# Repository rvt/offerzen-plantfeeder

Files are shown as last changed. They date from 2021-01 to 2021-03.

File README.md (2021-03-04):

# Offerzen plantfeeder

This is software + box for the offerzen plantfeeder [plant_tech_ams](https://github.com/OfferZen-Make/plant_tech_ams)
Check `platform.io` for pin layout as I had to change the pin number for the motor that somehow did not work.

### Support

* Deep sleep
* sending messages over MQTT
* A little scripting language
* Web based configurating of WiFi and MQTT configurations
* Loos wire detection so the motor won't keep running if your sensor wires breaks
* Hysteresis so your motor won't turn off/on around threshold value
* STl + OpenSCAD in box directory, you might need to modify dimentions for your need 

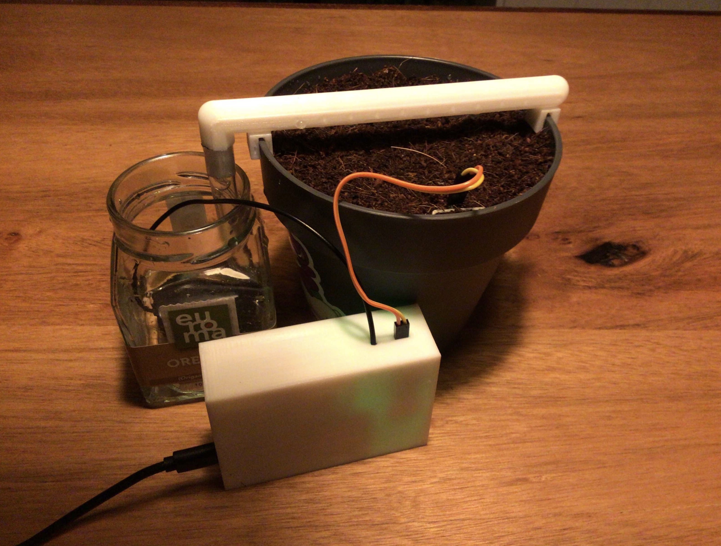
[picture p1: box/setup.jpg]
Total setup


## To Build you need PlatformIO

Use `platformio run --target upload -e default` to build and uploads.

Use `platformio run --target uploadfs -e default`to upload the needed filesystem.

## To Configure

* Look into your serial terminal and note your IP address and ID of your feeder.
* Use a webbrowser and fill in your WiFi and MQTT parameters

## PIN Connections

* Connection GPIO16 to the Reset pin
* Connect D8 to the VSS of the moisture sensor, we turn the moisture sensor on/off before and after a measurement to prevent corrision.
* Connect A0 to the analog out pin of the moisture sensor
* Connect GND of the moisture sensor to the GND of the ESP8266
* Connect D6 to the base (visa resistor) to the transistor to control the motor

## Set threshold values use MQTT and issue the following commands

* Topic: `plantfeeder/XXXXXXXX/config`
* Payload: `wet=400 dry=800`

Where `XXXXXXXX`is the ID for your plantfeeder, check a tool like MQTT Spy with plantfeeder/# to see your messages

When the measured value is below wet, then we are not adding any more water.
Consequently, when the measured value is above dry we will be adding more water;
* Dry should always be higher than wet, no protection against that
* The higher the measured value, the dryer the soil

No MQTT, No problem! Edit `data/hwCfg.conf`and fill in the values. (The L in front of the number is correct and not a typo, format is very strict, no spaces and integer only!)

## Enable/Disable deepSleep

To enable deepSleep

* Topic: `plantfeeder/XXXXXXXX/config`
* Payload: `deepSleepEnabled=1`

To disable deepSleep

* Topic: `plantfeeder/XXXXXXXX/config`
* Payload: `deepSleepEnabled=0`

## Scripting.

It uses a very little script and primitive to turn on/off the motor, see ´data/default.txt´ to change timings of the motor. If you want to add detecting of moisture levels within the script then look into
´scriptcontext.cpp´ and the ´scripting.cpp´ files or contact me and I can help.

To ensure that we don't keep the pump running on disconnect any value measured above `1020` is considered a disconnect and we won't run the engine to prevent flooding.

You can send on topic `plantfeeder/XXXXXXXX/load` with payload `/pump5.txt` to start the script (it will turn on the pump for 5 seconds) after that it will load the `default.txt` again. Be ware that during deep sleep nothing will happen, I have yet to test if after deep sleep it will load the script correctly (let me know).

## Deep Sleep
The device will enter deep sleep to conserve battery. you MUST connect GPIO16 to the RST pin with one of your dupont cable or else the device won't wake up. 
I did had issues with a powerpack that would turn of because the load was so low that the powerpack turned itself of.

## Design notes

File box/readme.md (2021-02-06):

## Box for your offzen plantfeeder

Slice the plantfeeder.stl and print with PLA. Infill set to 40% or higher and you should be good.

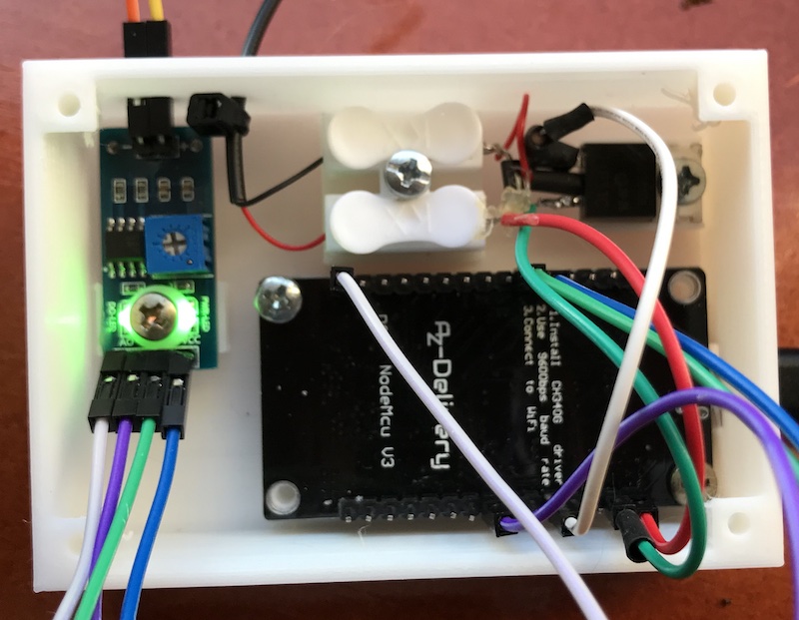
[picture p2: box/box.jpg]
Hardware wired up


* I added a flyback diode over the motor
* I added a resistor on the base of the TIP31C to limit currents.
* I have moved the terminal block more to the left to give the TIP31C more room

## Waterguide for your offzen plantfeeder

Slice the waterguide.stl and print with PLA, use a brim of 4mm use support for the sprout. CLean it up after printing.

Total setup

## New probe for your offzen plantfeeder

The soilProbe started to oxidize very quickly and I found it very sensitive.
This probe sticks much deeper in the soil making it much more sturdy and less sensitive.
Your A/D values will also be much lower (mine where like 100 for a wet soil instead of 300..400).
You properly want to modify the SCAD file before you print it to match the probe diameter (`probeDiam` in scad file)you have.
Mine where 6mm in diameter and I could solder them very easy. Perhaps some kopper wire you might have? 
Just print them with 100% infill and use a 3mm screw to put it together.

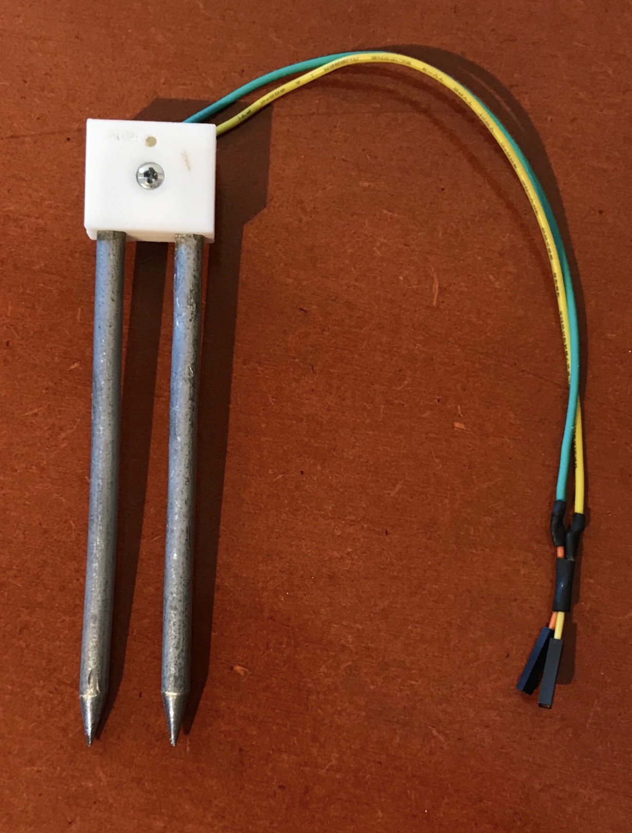
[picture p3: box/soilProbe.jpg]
soil probe


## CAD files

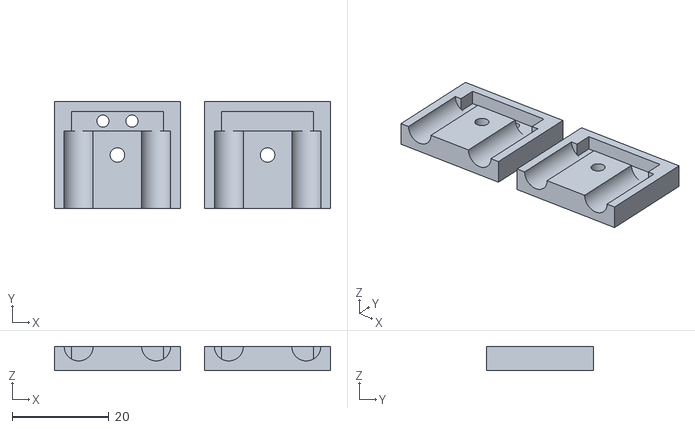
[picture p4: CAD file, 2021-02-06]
box/soilProbe.stl
57.0 x 22.0 x 5.00

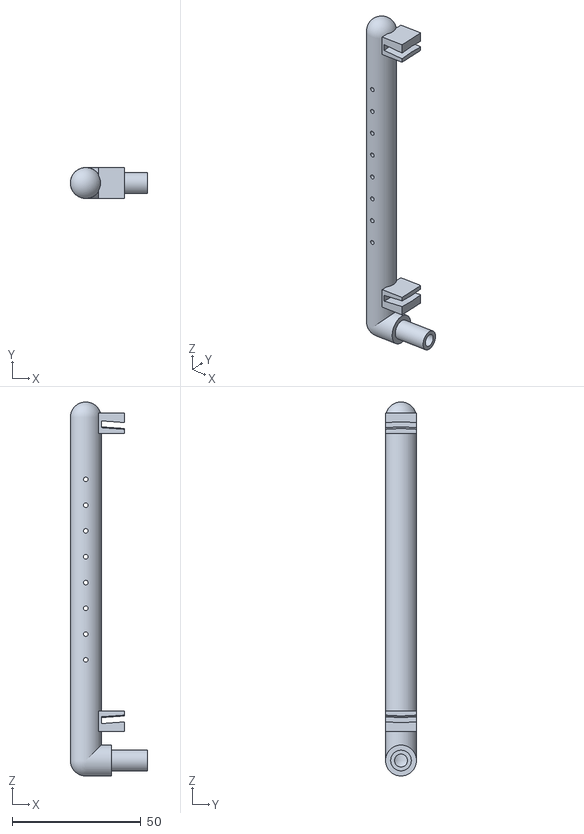
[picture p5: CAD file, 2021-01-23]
box/waterguide.stl
30.0 x 12.0 x 145.0

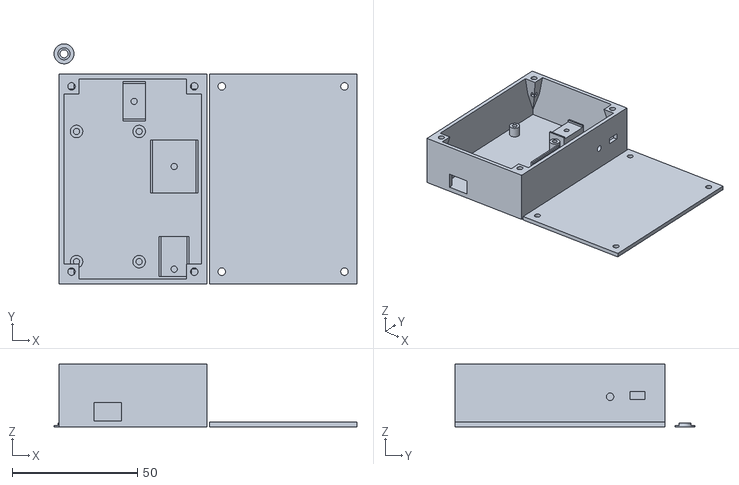
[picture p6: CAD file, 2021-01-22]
box/plantfeeder.stl
121.0 x 96.0 x 25.0

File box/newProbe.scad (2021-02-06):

$fn=60;

// Diameter of probe
probeDiam=6;        
// Spacing between probe
probeSpacing=16;
// THickness of wall
wall=2.0;

// Length of probe (Visual only)
probeLength=120;

// Diameter of screw
screwDiam=3;
// Height of screw head
screwHead=2.5;
// Diameter of screw head
screwHeadDiam=5.8;

///Offset probe from center of casing
probeEndOffset=5;

// Do not change below
wall2=wall*2;
probeSpacingD2=probeSpacing/2;
dim=[probeSpacing + probeDiam + wall2,probeEndOffset*2+4*2+wall2,probeDiam+wall2];

echo("Casing dimention ");
echo(dim);


soilProbe(true);
translate([dim.x+5,0,0]) soilProbe(false);

module soilProbe(bottom=true) {
    translate([0,0,dim.z/2])
    union() {
        difference() {
            union() {
                cube(dim, center=true);
                
            }
            union() {
                // Cut in half
                translate([0,0,dim.z/2]) cube(dim, center=true);

                // Room for Wire
                translate([0,probeEndOffset+2,0]) {
                    cube([probeSpacing+probeDiam/2,4,probeDiam], center=true);
                    if (bottom) {
                        translate([3,0,0]) cylinder(d=2.5,h=dim.z,center=true);
                        translate([-3,0,0]) cylinder(d=2.5,h=dim.z,center=true);
                    }
                }
                
                // Probe
                translate([probeSpacingD2,probeEndOffset,0]) probe();
                translate([-probeSpacingD2,probeEndOffset,0]) probe();      
                
                // screw Portion
                screw();
            }
        }

        %translate([probeSpacingD2,probeEndOffset,0]) probe();
        %translate([-probeSpacingD2,probeEndOffset,0]) probe();
    }
}


module screw() {
    cylinder(d=screwDiam,h=dim.z,center=true);
    translate([0,0,-dim.z/2+screwHead/2]) cylinder(d=screwHeadDiam,h=screwHead,center=true);
}    


module probe() {
    pointL=probeDiam*2.5;
    color([0.5,1,0.5]) rotate([90,0,0]) {
        cylinder(d=probeDiam,h=probeLength-pointL);
        translate([0,0,probeLength-pointL]) cylinder(d2=0, d1=probeDiam, h=probeDiam*2.5);
    }

}

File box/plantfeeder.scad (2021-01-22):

$fn=60;

boxX=55;
boxY=80;
boxZ=25;
wall=2;
screwSize=2.5;
diamMotorWire=3;

locationESP=[[5,7,0],[0,0,0]];
locationHydro=[[20+15,boxY-9,0], [0,0,90]];
locationTIPC31C=[[boxX-11,9,0], [0,0,0]];
locationKroon=[[boxX-11,boxY/2+5,0], [0,0,0]];
locationHoleMotor=[[boxX-5,boxY-20,boxZ-15], [0,90,0]];


// BOX&Stuff
difference() {
    union() {
        box();
        translate([-wall,-wall,-wall]) boxCornerTab(wall=wall,bottom=wall,innerWidth=boxX,innerLength=boxY,innerHeight=boxZ);
        TR(locationHydro) hygro(heightPcb=5, cut=false);
        TR(locationTIPC31C) color([1,0,0]) TIPC31C(heightPcb=5);
        TR(locationKroon) color([0,1,0]) kroon(heightPcb=5);
        TR(locationESP) esp8266_az(cut=false, heightPcb=5);
    }
    union() {
        translate([-wall,-wall,-wall]) boxCornerTab(wall=wall,bottom=wall,innerWidth=boxX,innerLength=boxY,innerHeight=boxZ,cut=true);
        TR(locationESP) esp8266_az(cut=true, heightPcb=5);
        TR(locationHydro) hygro(heightPcb=5, cut=true);
        TR(locationHoleMotor) cylinder(d=3,h=10);
    }
}

// Little ring
translate([0,boxY+10,-wall]) {
    difference() {
        union() {
            cylinder(d=3.2+4*0.4,h=1.5);
            cylinder(d=8,h=0.5);
        }
        cylinder(d=3.2,h=4);
    }
}

// LID
translate([60,0,0]) {
    difference() {
        lid();
            translate([-wall,-wall,-boxZ]) 
            boxCornerTab(wall=wall,bottom=wall,innerWidth=boxX,innerLength=boxY,innerHeight=boxZ,cut=true);
    }
}

module lid() {
    boxZ=wall;
    translate([boxX/2,boxY/2,boxZ/2-wall])
    cube([boxX+wall*2, boxY+wall*2, boxZ], center=true);
}


// Translate and Rotate
module TR(in) {
    translate(in[0]) rotate(in[1]) children();
}

module box() {
    translate([boxX/2,boxY/2,boxZ/2-wall])
        difference() {        
            cube([boxX+wall*2, boxY+wall*2, boxZ], center=true);
            translate([0,0,wall]) cube([boxX, boxY, boxZ], center=true);
        }
}

module esp8266_az(heightPcb=7, cut=false) {
    pos=[
        [0,0],
        [25,0],
        [0,52],
        [25,52]
    ];
    board=[[-3,-3],[31,57]];
    if (cut) {
        translate([0,0,heightPcb]+[0,0,-1.5]) 
        translate(board[0] + [0-11/2 + board[1].x/2,-17,0]) 
        translate([0,0,-3.2]) cube([11,17,7.4]);
    } else {
        %difference() {
            translate([0,0,heightPcb]) translate(board[0]) linear_extrude(height=1.5) square(board[1]);
            screwHoles(pos, heightPcb=heightPcb, diff=true);
        }
        screwHoles(pos, heightPcb=heightPcb, diff=false);
    }
}


module screwHoles(holes, heightPcb=5, diff=false) {
    for (idx = [ 0 : len(holes) - 1 ] ) {
        translate(holes[idx]) {
            difference() {
                union() {
                    if (diff==false)
                        cylinder(d=5,h=heightPcb-0.1,center=false);
                }
                cylinder(d=screwSize,h=heightPcb+5,center=false);
            }
        }
    }
}

module TIPC31C(heightPcb=3) {    
    b=[[10.4,16,heightPcb], [10.4/2,3,0]];        
    block(b);
}

module kroon(heightPcb=5) {
    b=[[17.4,21,heightPcb], [17.4/2,21/2,0]];        
    block(b);
}

module hygro(heightPcb=5, cut=false) {
    circuitThick = 1.5;
    board=[
        [-14.2/2,-31/2],
        [14.2,31],
    ];
    
    b=[[14.2,9,heightPcb], [14.2/2,9/2,0]];
    if (cut) {
        translate([-3,-15-31/2,-3/2 + heightPcb + 5.5]) cube([6,15,3]);
    } else {
        %translate([0,0,heightPcb]) 
            translate(board[0]) 
            linear_extrude(height=1.5) square(board[1]);
        translate([0,7,0]) block(b);
    }
}

module boxCornerTab(wall=2.0,bottom=2,innerWidth=30,innerLength=40,innerHeight=30,cut=false) {
    cornerHeight=20;
    b=[
        [[wall,wall,0],[0,0,0]],
        [[innerWidth+wall,wall,0],[0,0,90]],
        [[innerWidth+wall,innerLength+wall,0],[0,0,180]],
        [[wall,innerLength+wall,0],[0,0,270]]
    ];
    
    for (idx = [ 0 : len(b) - 1 ] ) {
        TR(b[idx]) corner(cut);
    }

    module corner(cut=false) {
        translate([0,0,innerHeight-cornerHeight])
        color([0.8,0.8,0.2]) 
        if (cut) {
            translate([3,3,cornerHeight/2]) cylinder(d=screwSize+0.5,h=innerHeight);
        } else {
            hull() {
                translate([0,0,cornerHeight]) cube([6,6,0.001]);
                translate([0,0,cornerHeight/2]) cube([4,4,0.001]);
                cube([0.1,0.1,0.001]);
            }        
        }
    }    
} 

module block(block) {
    translate([-block[0].x/2,-block[0].y/2]) {
        translate([-0.8,0,0]) cube([0.8, block[0].y, block[0].z+1]);
        translate([block[0].x,0,0]) cube([0.8, block[0].y, block[0].z+1]);    
        difference() {
            cube(block[0]);
            translate(block[1]) cylinder(d=screwSize,h=block[0].z+2);
        }
    }
}

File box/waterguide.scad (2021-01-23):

// Outher Diameter of the pot
outerDiamPot=118;
// Wall diameter of the pot
wallDiamPot=2.4;
// Diameter 
diamGuide=12;
// Distance between water holes
waterHoleDistance=9;
// Offset of cubes
offset=15;
//InnerTiameterTube;
tubeInnerDiam=8;
// Size water holes
sproudSize=1.6;

$fn = $preview ? 12 : 72;

difference() {
    union() {
        pipe(length=outerDiamPot+offset,i=diamGuide-3.2,o=diamGuide,cap=[2,2],cut=false);
        rotate([0,90,0]) pipe(o=diamGuide,cap=[2,0],length=10,cut=false);
        translate([10,0,0]) rotate([0,90,0]) pipe(o=tubeInnerDiam,i=5,cap=[0,0],length=14,cut=false);
        // Block to hold pot
        blockOffset=offset-8/2;
        translate([0,-diamGuide/2,blockOffset]) 
            cube([15,diamGuide,8]);
        translate([0,-diamGuide/2,outerDiamPot-wallDiamPot+blockOffset]) 
            cube([15,diamGuide,8]);
    }
    union() {
        //translate([-250,0,-250]) cube([500,20,500]);
        pipe(length=outerDiamPot+15,i=diamGuide-4,o=diamGuide+1,cap=[2,2],cut=true);
        rotate([0,90,0]) pipe(cap=[2,0],i=6,o=10,length=10,cut=true);
       
        // Water holdes
        offsetToCenterHoles=(outerDiamPot-8*waterHoleDistance)/2;
        translate([0,0,offset+offsetToCenterHoles]) {
            mirror([0,1,0]) waterHoles();
            waterHoles();
        }
        
        translate([diamGuide/2,0,offset]) potRing();
    }
}

module waterHoles() {
    for ( i = [0 : 4] ){
        color([0,1,0]) translate([0, 0, i*waterHoleDistance*2])
        rotate([90,00,15]) cylinder(d=sproudSize,h=20);
    }
    for ( i = [0 : 3] ){
        color([0,0,1]) translate([0, 0, i*waterHoleDistance*2+waterHoleDistance])
        rotate([90,00,00]) cylinder(d=sproudSize,h=20);
    }
}

module potRing() {
    height=20;
    translate([height/2,0,outerDiamPot/2-wallDiamPot/2]) 
    rotate([0,90,0]) difference() {
        dInner=outerDiamPot-(wallDiamPot+0.2)*2;
        cylinder(d1=outerDiamPot,d2=outerDiamPot-3,h=height,center=true);
        cylinder(d1=dInner,d2=dInner-3,h=21,center=true);
    }
}

module pipe(i=5,o=10,length=50,cap=[0,0], cut=false) {
    translate([0,0,length/2]) {
        difference() {
            union() {                
                if (cut==false) {
                    cylinder(d=o,h=length,center=true);
                    if (cap[0]>0) {
                        cap(o,-1,cap[0],false);
                    }   
                    if (cap[1]>0) {
                        cap(o,1,cap[1],false);
                    }    
                }
            }
            union() {
                cylinder(d=i,h=length,center=true);
                if (cap[0]>0) {
                    cap(i,-1,cap[0],true);
                }   
                if (cap[1]>0) {
                    cap(i,1,cap[1],true);
                }   
            }
        } 
    }
    

    module cap(diam,pos,capStyle,diff) {
        translate([0,0,pos*length/2]) {
            if (capStyle==1 && diff==false) {
                translate([0,0,pos*1]) cylinder(d=diam,h=2,center=true);
            }
            if (capStyle==2) sphere(d=diam);
        }
    }
 
}

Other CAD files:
box/soilProbe.scad

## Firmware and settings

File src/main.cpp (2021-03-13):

/*
 */
#include <memory>
#include <cstring>
#include <vector>

#include "network.hpp"
extern "C" {
#include <crc16.h>
}

#include <FS.h>
#include <scripting.hpp>
#define WIFI_getChipId() ESP.getChipId()

#define FileSystemFS SPIFFS
#define FileSystemFSBegin() SPIFFS.begin()

#include <WiFiManager.h> // https://github.com/tzapu/WiFiManager
#include <propertyutils.hpp>
#include <optparser.hpp>
#include <oneshot.hpp>
#include <utils.h>

#include <config.hpp>

#include <StreamUtils.h>
typedef PropertyValue PV;

// of transitions
uint32_t slotCounterPerTick = 1;

// Number calls per second we will be handling
constexpr uint8_t TICKS_PER_SECOND        = 100;
constexpr uint16_t TICK_PERIOD_CALLBACK = (1000 / TICKS_PER_SECOND);
constexpr uint8_t LINE_BUFFER_SIZE = 128;
constexpr uint8_t PARAMETER_SIZE = 16;

// Keep track when the last time we ran the effect state changes
uint32_t effectPeriodStartMillis = 0;

// WiFI Manager
WiFiManager wm;
#define MQTT_SERVER_LENGTH 40
#define MQTT_PORT_LENGTH 5
#define MQTT_USERNAME_LENGTH 18
#define MQTT_PASSWORD_LENGTH 18
WiFiManagerParameter wm_mqtt_server("server", "mqtt server", "", MQTT_SERVER_LENGTH);
WiFiManagerParameter wm_mqtt_port("port", "mqtt port", "", MQTT_PORT_LENGTH);
WiFiManagerParameter wm_mqtt_user("user", "mqtt username", "", MQTT_USERNAME_LENGTH);

const char _customHtml_hidden[] = "type=\"password\"";
WiFiManagerParameter wm_mqtt_password("input", "mqtt password", "", MQTT_PASSWORD_LENGTH, _customHtml_hidden, WFM_LABEL_AFTER);


Properties controllerConfig;
Properties hwConfig;

bool controllerConfigModified = false;
bool hwConfigModified = false;
// We dont receive retained messages untill we are really only, this boolean will be true when we are
bool mqtt_onlineRecieved = false;

// CRC value of last update to MQTT
uint16_t lastMeasurementCRC = 0;
uint32_t shouldRestart = 0;        // Indicate that a service requested an restart. Set to millies() of current time and it will restart 5000ms later



///////////////////////////////////////////////////////////////////////////
//  Sending MQTT max once per seco
///////////////////////////////////////////////////////////////////////////

void publishStatusToMqtt();
OneShot publishStatusToMqttOneShot{
    5000,
    []() {
    },
    []() {
        publishStatusToMqtt();
        publishStatusToMqttOneShot.reset();
    },
    []() {
        return true;
    }
};

OneShot publishStatusToMqttFastOneShot{
    500,
    []() {
        publishStatusToMqtt();
    },
    []() {
        publishStatusToMqtt();

        if (scripting_context()->pump()) {
            publishStatusToMqttOneShot.reset();
        }
    },
    []() {
        return scripting_context()->pump();
    }
};

///////////////////////////////////////////////////////////////////////////
//  Loading/Saving of Properties
///////////////////////////////////////////////////////////////////////////
bool loadConfig(const char* filename, Properties& properties, bool serial) {
    bool ret = false;

    if (FileSystemFSBegin()) {
        Serial.println("mounted file system");

        if (FileSystemFS.exists(filename)) {
            //file exists, reading and loading
            File configFile = FileSystemFS.open(filename, "r");

            if (configFile) {
                Serial.print(F("Loading config : "));
                Serial.println(filename);
                deserializeProperties<LINE_BUFFER_SIZE>(configFile, properties);

                if (serial) {
                    serializeProperties<LINE_BUFFER_SIZE>(Serial, properties);
                }
            }

            configFile.close();
        } else {
            Serial.print(F("File not found: "));
            Serial.println(filename);
        }

        // FileSystemFS.end();
    } else {
        Serial.print(F("Failed to begin FileSystemFS"));
    }

    return ret;
}

/**
 * Store custom oarameter configuration in FileSystemFS
 */
bool saveConfig(const char* filename, Properties& properties, bool serial) {
    bool ret = false;

    if (FileSystemFSBegin()) {
        FileSystemFS.remove(filename);
        File configFile = FileSystemFS.open(filename, "w");

        if (configFile) {
            Serial.print(F("Saving config : "));
            Serial.println(filename);
            serializeProperties<LINE_BUFFER_SIZE>(configFile, properties);

            if (serial) {
                serializeProperties<LINE_BUFFER_SIZE>(Serial, properties, false);
            }

            ret = true;
        } else {
            Serial.print(F("Failed to write file"));
            Serial.println(filename);
        }

        configFile.close();
        //    FileSystemFS.end();
    }

    return ret;
}

void publishStatusToMqtt();
// Return true if network was connected but deep sleep disabled
// Returns false if network was not connected yet
bool deep_sleep(uint32_t time_us) {
    if (hwConfigModified) {
        saveConfig(CONFIG_FILENAME, hwConfig, true);
        hwConfigModified = false;
    }

    if (controllerConfigModified) {
        saveConfig(CONTROLLER_CONFIG_FILENAME, controllerConfig, false);
        controllerConfigModified = false;
    }

    if (network_is_connected() && mqtt_onlineRecieved) {
        // Give the network some time to handle any messages
        // Just in case we got fast connections hand handling did not proceed
        uint8_t loopCounter=0;
        while (loopCounter<100) {
            network_handle();
            delay(10);
            loopCounter++;
        }
        if (controllerConfig.get("deepSleepEnabled")) {
            publishStatusToMqtt();
            network_flush();
            network_shutdown();
            FileSystemFS.end();
            Serial.print("Good Night, see you in ");
            Serial.print(time_us / 1000000);
            Serial.println(" seconds");
            ESP.deepSleep(time_us);
        } else  {
            Serial.println("Deep sleep disabled.");
        }

        return true;
    } else {
        Serial.println("No network, will not sleep.");
    }

    return false;
}

///////////////////////////////////////////////////////////////////////////
//  MQTT
///////////////////////////////////////////////////////////////////////////
/*
* Publish current status
*/
void publishStatusToMqtt() {
    if (scripting_context() == nullptr || !scripting_context()->validMeasurement()) {
        return;
    }

    const char format[] = "pump=%d hygro=%d wet=%d dry=%d cycle=%d";
    char buffer[sizeof(format) + 2 + 2 + 2 + 2 - 1 + 8];

    sprintf(buffer,
            format,
            scripting_context()->pump(),
            scripting_context()->currentValue(),
            scripting_context()->wetThreshold(),
            scripting_context()->dryThreshold(),
            scripting_context()->wateringCycle()
           );


    // Quick hack to only update when data actually changed
    uint16_t thisCrc = crc16((uint8_t*)buffer, std::strlen(buffer));

    if (thisCrc != lastMeasurementCRC) {
        if (network_publishToMQTT("status", buffer, true)) {
            lastMeasurementCRC = thisCrc;
        }
    }
}

/**
 * Handle incomming MQTT requests
 */
void handleCmd(const char* topic, const char* p_payload) {
    auto topicPos = topic + strlen(controllerConfig.get("mqttBaseTopic"));
    Serial.print(F("Handle command : "));
    Serial.print(topicPos);
    Serial.print(F(" : "));
    Serial.println(p_payload);

    // Look for a temperature setPoint topic
    char payloadBuffer[LINE_BUFFER_SIZE];
    strncpy(payloadBuffer, p_payload, sizeof(payloadBuffer));

    if (strstr(topicPos, "config") != nullptr) {
        OptParser::get(payloadBuffer, [&](OptValue v) {
            if (strcmp(v.key(), "wet") == 0) {
                hwConfig.put("wetThreshold", PV((int16_t)v));
                hwConfigModified = true;
            } else if (strcmp(v.key(), "dry") == 0) {
                hwConfig.put("dryThreshold", PV((int16_t)v));
                hwConfigModified = true;
            } else if (strcmp(v.key(), "deepSleepEnabled") == 0) {
                controllerConfig.put("deepSleepEnabled", PV((bool)v));
                controllerConfigModified = true;
            } else if (strcmp(v.key(), "pauseForOTA") == 0) {
                controllerConfig.put("pauseForOTA", PV((bool)v));
                controllerConfigModified = true;
            }        
        });
    }

    if (strstr(topicPos, "lastwill") != nullptr) {
        if (strcmp(payloadBuffer, MQTT_LASTWILL_ONLINE) == 0) {
            mqtt_onlineRecieved = true;
        }
    }

    if (strstr(topicPos, "load") != nullptr) {
        scripting_load(payloadBuffer);
    }

    if (strstr(topicPos, "sleep") != nullptr) {
        deep_sleep(atol(payloadBuffer));
    }

    if (strstr(topicPos, "reset") != nullptr) {
        if (strcmp(payloadBuffer, "1") == 0) {
            shouldRestart = millis();
        }
    }
}

/**
 * Initialise MQTT and variables
 */
void setupMQTTCallback() {
    network_mqtt_callback([](char* p_topic, byte * p_payload, uint16_t p_length) {
        char mqttReceiveBuffer[LINE_BUFFER_SIZE];
        // Serial.println(p_topic);

        if (p_length >= sizeof(mqttReceiveBuffer)) {
            return;
        }

        strncpy(mqttReceiveBuffer, (char*)p_payload, LINE_BUFFER_SIZE);
        mqttReceiveBuffer[p_length] = 0;
        handleCmd(p_topic, mqttReceiveBuffer);
    });

}


///////////////////////////////////////////////////////////////////////////
//  Handle script context
///////////////////////////////////////////////////////////////////////////
void handleScriptContext() {
    int8_t handle = scripting_handle();

    if (scripting_context() != nullptr) {
        if (scripting_context()->measuring()) {
            scripting_context()->currentValue(analogRead(MOISTA_PIN));
            bool wateringCycleModified = (bool)hwConfig.get("wateringCycle") != scripting_context()->wateringCycle();
            if (wateringCycleModified) {
                hwConfigModified = wateringCycleModified;
                hwConfig.put("wateringCycle", PropertyValue(scripting_context()->wateringCycle()));
            }
        }

        if (scripting_context()->pump()) {
            publishStatusToMqttFastOneShot.start();
        }
    }

    switch (handle) {
        case 0:
            digitalWrite(PUMP_PIN, false);
            digitalWrite(PROBEPWR_PIN, false);
            Serial.println("Script ended");
            scripting_load("/default.txt");
            break;

        case 1:
            digitalWrite(PROBEPWR_PIN, scripting_context()->probe());
            digitalWrite(PUMP_PIN, scripting_context()->pump());
    }
}


///////////////////////////////////////////////////////////////////////////
//  IOHardware
///////////////////////////////////////////////////////////////////////////
void setupIOHardware() {
    // Pump Pin
    pinMode(PUMP_PIN, OUTPUT);
    digitalWrite(PUMP_PIN, false);

    // Power pin of probe
    pinMode(PROBEPWR_PIN, OUTPUT);
    digitalWrite(PROBEPWR_PIN, false);
}

///////////////////////////////////////////////////////////////////////////
//  Webserver/WIFIManager
///////////////////////////////////////////////////////////////////////////
void saveParamCallback() {
    Serial.println("[CALLBACK] saveParamCallback fired");

    if (std::strlen(wm_mqtt_server.getValue()) > 0) {
        controllerConfig.put("mqttServer", PV(wm_mqtt_server.getValue()));
        controllerConfig.put("mqttPort", PV(std::atoi(wm_mqtt_port.getValue())));
        controllerConfig.put("mqttUsername", PV(wm_mqtt_user.getValue()));
        controllerConfig.put("mqttPassword", PV(wm_mqtt_password.getValue()));
        controllerConfigModified = true;
        // Redirect from MQTT so on the next reconnect we pickup new values
        network_mqtt_disconnect();
        // Send redirect back to param page
        wm.server->sendHeader(F("Location"), F("/param?"), true);
        wm.server->send(302, FPSTR(HTTP_HEAD_CT2), "");   // Empty content inhibits Content-length header so we have to close the socket ourselves.
        wm.server->client().stop();
    }
}

/**
 * Setup the wifimanager and configuration page
 */
void setupWifiManager() {
    char port[6];
    snprintf(port, sizeof(port), "%d", (int16_t)controllerConfig.get("mqttPort"));
    wm_mqtt_port.setValue(port, MQTT_PORT_LENGTH);
    wm_mqtt_password.setValue(controllerConfig.get("mqttPassword"), MQTT_PASSWORD_LENGTH);
    wm_mqtt_user.setValue(controllerConfig.get("mqttUsername"), MQTT_USERNAME_LENGTH);
    wm_mqtt_server.setValue(controllerConfig.get("mqttServer"), MQTT_SERVER_LENGTH);

    wm.addParameter(&wm_mqtt_server);
    wm.addParameter(&wm_mqtt_port);
    wm.addParameter(&wm_mqtt_user);
    wm.addParameter(&wm_mqtt_password);

    /////////////////
    // set country
    wm.setClass("invert");
    wm.setCountry("US"); // setting wifi country seems to improve OSX soft ap connectivity, may help others as well

    // Set configuration portal
    wm.setShowStaticFields(false);
    wm.setConfigPortalBlocking(false); // Must be blocking or else AP stays active
    wm.setDebugOutput(false);
    wm.setSaveParamsCallback(saveParamCallback);
    wm.setHostname(controllerConfig.get("mqttClientID"));
    std::vector<const char*> menu = {"wifi", "wifinoscan", "info", "param", "sep", "erase", "restart"};
    wm.setMenu(menu);

    wm.startWebPortal();
    wm.autoConnect(controllerConfig.get("mqttClientID"));
}

///////////////////////////////////////////////////////////////////////////
//  SETUP and LOOP
///////////////////////////////////////////////////////////////////////////

void setDefaultConfigurations() {
    // controllerConfig
    char chipHexBuffer[9];
    snprintf(chipHexBuffer, sizeof(chipHexBuffer), "%08X", WIFI_getChipId());

    char mqttClientID[24];
    snprintf(mqttClientID, sizeof(mqttClientID), MQTT_NAME "_%s", chipHexBuffer);

    char mqttBaseTopic[24];
    snprintf(mqttBaseTopic, sizeof(mqttBaseTopic), MQTT_NAME "/%s", chipHexBuffer);

    char mqttLastWillTopic[64];
    snprintf(mqttLastWillTopic, sizeof(mqttLastWillTopic), "%s/%s", mqttBaseTopic, MQTT_LASTWILL_TOPIC);

    controllerConfigModified |= controllerConfig.putNotContains("mqttServer", PV(""));
    controllerConfigModified |= controllerConfig.putNotContains("mqttUsername", PV(""));
    controllerConfigModified |= controllerConfig.putNotContains("mqttPassword", PV(""));
    controllerConfigModified |= controllerConfig.putNotContains("mqttPort", PV(1883));
    controllerConfigModified |= controllerConfig.putNotContains("pauseForOTA", PV(false));
    controllerConfigModified |= controllerConfig.putNotContains("deepSleepEnabled", PV(true));

    controllerConfig.put("mqttClientID", PV(mqttClientID));
    controllerConfig.put("mqttBaseTopic", PV(mqttBaseTopic));
    controllerConfig.put("mqttLastWillTopic", PV(mqttLastWillTopic));

    // hwConfig
    hwConfigModified |= hwConfig.putNotContains("dryThreshold", PV(800));
    hwConfigModified |= hwConfig.putNotContains("wetThreshold", PV(600));
    hwConfigModified |= hwConfig.putNotContains("wateringCycle", PV(true));
}

void setup() {
    // Enable serial port
    Serial.begin(115200);
    delay(500); // SOmething buggy in the ESP8266MOD

    while (!Serial) {
        delay(20);
    }

    // load configurations
    loadConfig(CONTROLLER_CONFIG_FILENAME, controllerConfig, false);
    loadConfig(CONFIG_FILENAME, hwConfig, true);
    setDefaultConfigurations();

    scripting_init();
    scripting_load("/default.txt");

    setupIOHardware();
    setupMQTTCallback();
    network_init();
    setupWifiManager();
    effectPeriodStartMillis = millis();
}

uint8_t maxSlots = 255;
void loop() {
    const uint32_t currentMillis = millis();

    if (currentMillis - effectPeriodStartMillis >= TICK_PERIOD_CALLBACK) {
        effectPeriodStartMillis += TICK_PERIOD_CALLBACK;
        slotCounterPerTick++;

        handleScriptContext();

        if (scripting_context() != nullptr) {
            publishStatusToMqttOneShot.handle(currentMillis);
            publishStatusToMqttFastOneShot.handle(currentMillis);
        }

        // Maintenance stuff
        uint8_t slot50 = 0;

        if (slotCounterPerTick % maxSlots == slot50++) {
            network_handle();
        } else if (slotCounterPerTick % maxSlots == slot50++) {
            if (controllerConfigModified) {
                controllerConfigModified = false;
                saveConfig(CONTROLLER_CONFIG_FILENAME, controllerConfig, false);
            }
        } else if (slotCounterPerTick % maxSlots == slot50++) {
            if (hwConfigModified) {
                hwConfigModified = false;
                saveConfig(CONFIG_FILENAME, hwConfig, true);
            }

        } else if (slotCounterPerTick % maxSlots == slot50++) {
            wm.process();
        } else if (slotCounterPerTick % maxSlots == slot50++) {
            if (shouldRestart != 0 && (currentMillis - shouldRestart >= 5000)) {
                shouldRestart = 0;
                ESP.restart();
            }
        } else if (slotCounterPerTick % maxSlots == slot50++) {
            if (scripting_context() != nullptr && scripting_context()->m_deepSleepSec != 0) {
                if (deep_sleep(scripting_context()->m_deepSleepSec * 1000000)) {
                    scripting_context()->m_deepSleepSec = 0;
                }
            }
        } else {
            maxSlots = slot50;
        }
    }
}

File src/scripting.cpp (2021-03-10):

#include <vector>
#include <Arduino.h>
#include "scripting.hpp"
#include <scriptrunner.hpp>
#include "scriptcontext.hpp"
#include <propertyutils.hpp>

#include <FS.h>
#define FileSystemFS SPIFFS
#define FileSystemFSBegin() SPIFFS.begin()

/*********************
 *      EXTERNALS
 *********************/
extern Properties hwConfig;
extern bool hwConfigModified;
extern void deep_sleep(uint32_t time);

/*********************
 *      Variables
 *********************/
constexpr uint8_t SCRIPT_LINE_SIZE_MAX = 32;

static ScriptContext* scriptContext{nullptr};
static ScriptRunner<ScriptContext>* scriptRunner = nullptr;
static char scriptContextFileToLoad[32]; // See note for handleScriptContext()

using namespace rvt::scriptrunner;

bool getBoolValue(const char* value, uint8_t pos) {
    bool rValue = false;
    OptParser::get<SCRIPT_LINE_SIZE_MAX>(value, ',', [&](const OptValue & parsed) {
        if (parsed.pos() == pos) {
            rValue = (bool)parsed;
        }
    });
    return rValue;
}

void scripting_init() {
    std::vector<Command<ScriptContext>*> commands;

    commands.push_back(new Command<ScriptContext> {"serial", [](const char* value, ScriptContext & context) {
        Serial.println(value);
        Serial.flush();
        return true;
    }
                                                  });

    commands.push_back(new Command<ScriptContext> {"pump", [](const char* value, ScriptContext & context) {
        context.pump(getBoolValue(value, 0));
        return true;
    }
                                                  });

    commands.push_back(new Command<ScriptContext> {"decideAboveDry", [&](const char* value, ScriptContext & context) {
        if (!context.isAboveDry()) {
            context.jump(value);
        }

        return true;
    }
                                                  });

    commands.push_back(new Command<ScriptContext> {"measure", [&](const char* value, ScriptContext & context) {
        context.measuring(getBoolValue(value, 0));
        return true;
    }
                                                  });

    commands.push_back(new Command<ScriptContext> {"decideBelowWet", [&](const char* value, ScriptContext & context) {
        if (!context.isBelowWet()) {
            context.jump(value);
        }

        return true;
    }
                                                  });

    commands.push_back(new Command<ScriptContext> {"wateringCycle", [&](const char* value, ScriptContext & context) {
        if (!context.wateringCycle()) {
            context.jump(value);
        }

        return true;
    }
                                                  });

    commands.push_back(new Command<ScriptContext> {"probe", [&](const char* value, ScriptContext & context) {
        context.probe(getBoolValue(value, 0));
        return true;
    }
                                                  });

    commands.push_back(new Command<ScriptContext> {"sleepSec", [&](const char* value, ScriptContext & context) {
        scriptContext->m_deepSleepSec = atol(value);
        return true;
    }
                                                  });

    commands.push_back(new Command<ScriptContext> {"load", [&](const char* value, ScriptContext & context) {
        strncpy(scriptContextFileToLoad, value, sizeof(scriptContextFileToLoad));
        return true;
    }
                                                  });

    scriptRunner = new ScriptRunner<ScriptContext> {commands};
}

void load_script() {
    char buffer[1024];
    uint16_t pos = 0;

    if (FileSystemFS.exists(scriptContextFileToLoad)) {
        //file exists, reading and loading
        File configFile = FileSystemFS.open(scriptContextFileToLoad, "r");

        while (configFile.available()) {
            buffer[pos++] = char(configFile.read());
        }

        buffer[pos++] = 0;
        configFile.close();
        Serial.print(F("Loaded : "));
        Serial.println(scriptContextFileToLoad);
        delete scriptContext;
        scriptContext = new ScriptContext{buffer, (bool)hwConfig.get("wateringCycle"), (int16_t)hwConfig.get("dryThreshold"), (int16_t)hwConfig.get("wetThreshold")};
    } else {
        Serial.print(F("File not found: "));
        Serial.println(scriptContextFileToLoad);
    }

    scriptContextFileToLoad[0] = 0;
}

void scripting_load(const char* value) {
    strncpy(scriptContextFileToLoad, value, sizeof(scriptContextFileToLoad));
}

int8_t scripting_handle() {
    if (strlen(scriptContextFileToLoad) != 0) {
        // Note: Never run handle right after loading a script
        load_script();
        return 1;
    } else if (scriptContext == nullptr) {
        return -1;
    } else if (scriptRunner->handle(*scriptContext, true)) {
        return 1;
    } else {
        delete scriptContext;
        scriptContext = nullptr;
        return 0;
    }
}

ScriptContext* scripting_context() {
    return scriptContext;
}

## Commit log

2021-01-22 DOcumentation + Boxes
    [plantfeeder.scad, plantfeeder.stl]
2021-01-23 Update scriptcontext.hpp
    Better logic on deciding when to turn on the pump
2021-01-23 Added STL for watering system Made decission when to wate rmore logical
    [waterguide.scad, waterguide.stl]
2021-01-23 Optmise deep sleep Better version of water sproud
    [waterguide.scad]
2021-02-01 Better naming and small bugfix that during startup made the pump run
    [main.cpp, scripting.cpp]
2021-02-01 Better notification to MQTT of pump status
2021-02-01 Fix how to jump
    [scripting.cpp]
2021-02-06 OpenSCAD fileOpenSCAD file for new probe
    [newProbe.scad, newProbe.stl]
2021-02-06 rename probe
    [soilProbe.scad, soilProbe.stl]
2021-02-11 Enable/Disable moisture probe to prevent corrosion.
    [main.cpp, scripting.cpp]
2021-02-24 Bugfix on deep_sleep Bugfix on measured value when probe is off
    [main.cpp, scripting.cpp]
2021-02-25 More small fixes and corrections
    [main.cpp, scripting.cpp]
2021-03-07 Using oneShot timer to update MQTT less often, even if it wants it
2021-03-13 Dont keep CRC if MQTT send failed
    [main.cpp]
